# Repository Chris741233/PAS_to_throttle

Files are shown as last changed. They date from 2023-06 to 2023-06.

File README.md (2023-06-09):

# E-bike PAS to throttle converter

Allows you to install a PAS on e-bikes that do not have this port. For those who already have one managed by the controller, also makes it possible to make the starts much more responsive (!) and offers more possibilities of adjustments. A throttle/accelerator input on the controller is required (if no, see also links below).

Permet d'installer un PAS sur les e-bike ne possédant pas ce port. Pour ceux qui en ont déjà un géré par le controleur, permet également de rendre beaucoup plus réactif les démarages (!) et offre plus de possibilités de réglages.
Une entrée throttle/accélérateur sur le controleur est nécessaire (le cas échéant voir aussi liens ci-dessous).

- Conversion de la sortie PAS vers l'entrée throttle (gachette / accélérateur).  
- Possibilité d'utiliser ou non l'assistance proportionnelle en fonction de la vitesse de pédalage.  
- En option inversersion de l'aide  = Plus d'aide en pédalage lent que rapide  
- Le code vérifie le sens de pédalage (pas d'assistance en pédalage arrière !)
- Prise en charge d'une gachette (prioritaire) en option

**see also**  
- [PAS analyzer](https://github.com/Chris741233/PAS_analyzer)
- [Throttle to PAS](https://github.com/Chris741233/throttle-to-PAS)
- [Button to PAS (with cruise in option)](https://github.com/Chris741233/button-to-PAS)

**Discussion sur le forum Cyclurba**  
[Cyclurba](https://cyclurba.fr/forum/forum_discussion.php?from=41&messageID=742211#)

---

 #### Wiring (Arduino Uno/Nano, +5V)

<p align="left">
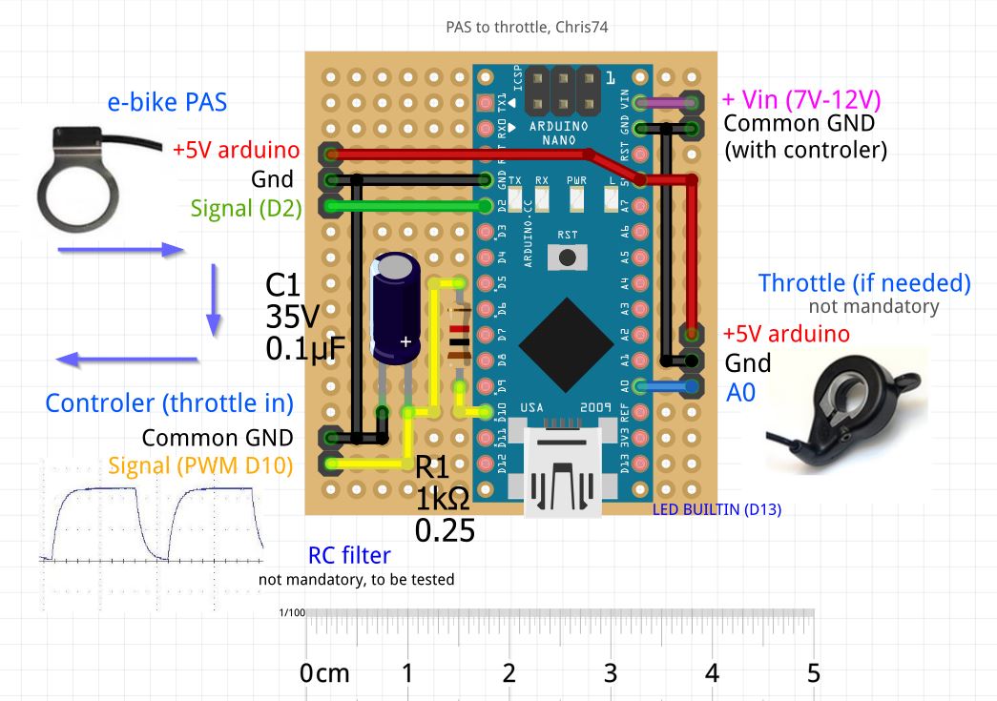
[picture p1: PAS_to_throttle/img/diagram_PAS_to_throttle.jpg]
  
</p>

<p align="left">
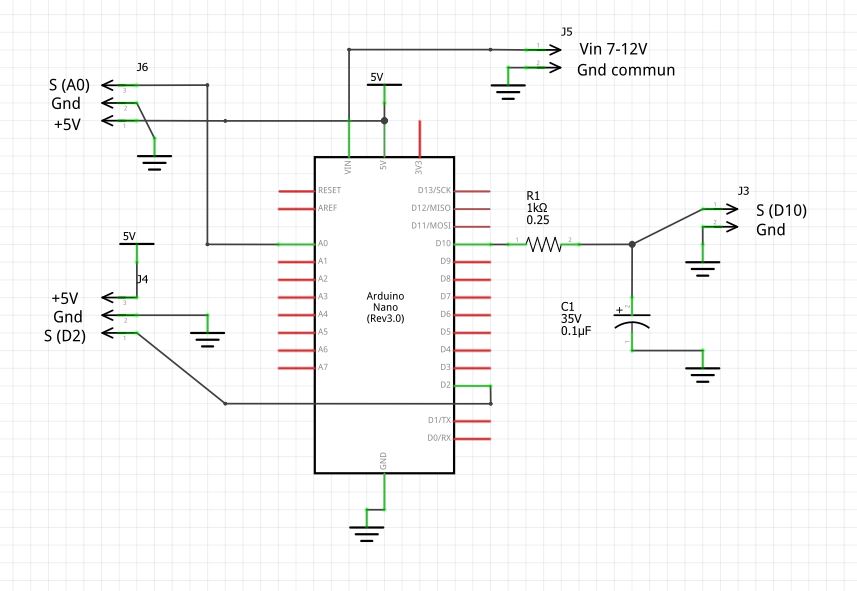
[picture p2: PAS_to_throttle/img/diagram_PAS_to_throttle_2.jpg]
  
</p>

---

#### Usage
*Adjust constants at the beginning of code*\
Régler les constantes en début de code

```
-- Setting ---
#define USE_PROPORTIONAL    0   // use proportional assistance ? 1=yes, 0=no (if no, use only On-Off assistance with full PWM)
#define INVERSE_ASSISTANCE  0   // if proportional, inverse assistance ? 1=yes, 0=no (if yes, slow pedaling = more assistance !)
#define USE_THUMB_THROTTLE  0   // thumb throttle is instaled (see diagram) ? 1=yes, 0=no (throttle priority on the PAS)

const int  NB_MAGNETS =  6;     // How many magnets on PAS ?  (default 6)
const float V_REF =     4.95;   // Arduino +5V pin reference (=PWM high level) - To test! (default 5.00)
const float V_MIN_THR = 1.10;   // throttle min voltage (default 1.1V --- no push)
const float V_MAX_THR = 3.50;   // throttle max voltage (default 3.5V --- full  push)

// throttle (if instaled) --> ADC value, see debug Serial in loop !
const int   TR_ADC_MIN    = 220;    // throttle min - marge ajoutee dans map()
const int   TR_ADC_MAX    = 859;    // throttle max - marge deduite dans map()
const int TR_ADC_MARGIN   = 15;     // margin throttle before send signal PWM and as a deduction of TR_MAX

const int  RPM_TO_START = 10;   // How many RPM to start assistance ? (with default 10, start is normally fast enough)
// --> more rpm = less ms
const int START_PULSES  = 0;    // Number of pulses (magnet) needed before turning On (0 = fastest)
// if use_proportional, RPM value for maping PWM out --> cf map() in void turnOn()
const int RPM_MIN = 25;         // min rpm  (default 25rpm)
const int RPM_MAX = 65;         // max rpm  (default 65rpm)
// interval timer loop: Check RPM, Turn Off, and debug Serial
const int SCAN_INTERVAL = 250;   // default 250, if assistance cut too fast when stop pedaling, put const to ~500ms or 1000ms

```

#### Oscillo and debug Serial
<p align="left">
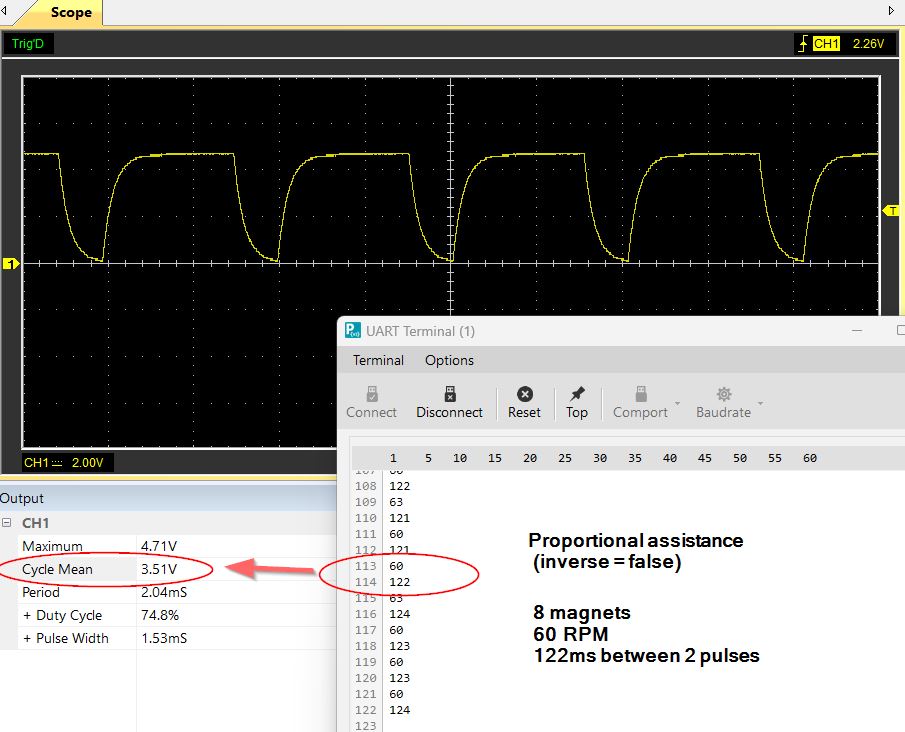
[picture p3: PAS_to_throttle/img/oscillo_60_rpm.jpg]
Oscillo
  
</p>

<br>

<p align="left">
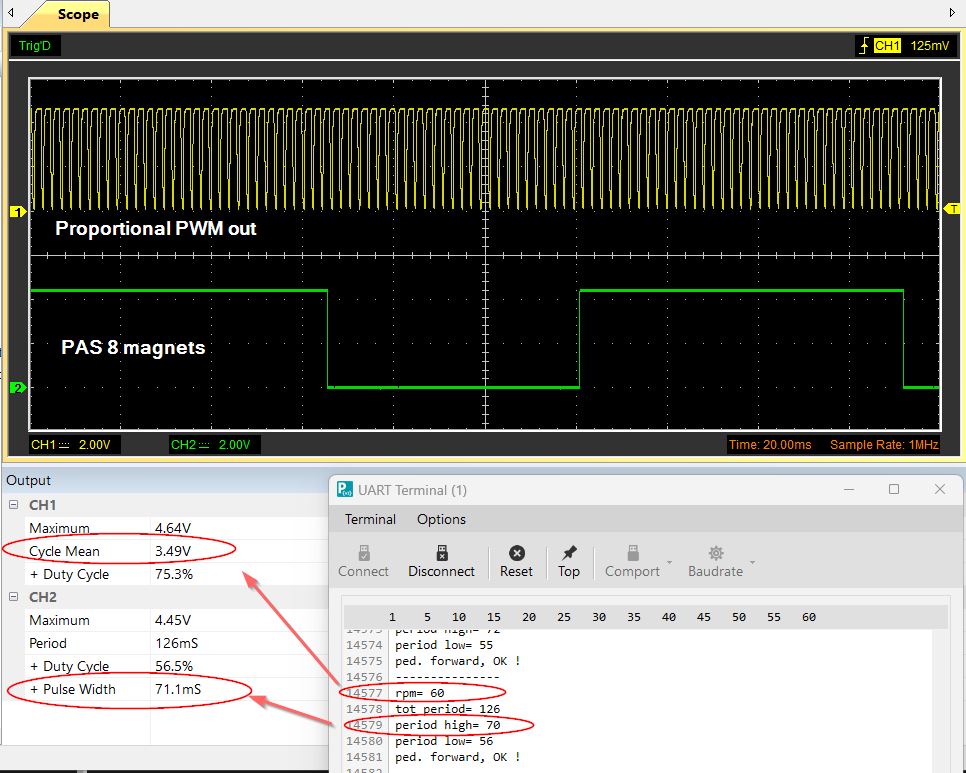
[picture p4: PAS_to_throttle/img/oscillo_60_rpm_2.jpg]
Oscillo
  
</p>

---

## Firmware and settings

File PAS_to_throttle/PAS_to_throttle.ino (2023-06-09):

/******************************************************************
Created with PROGRAMINO IDE for Arduino - 02.06.2023 | 10:21:23
Project     :
Libraries   :
Author      :  Chris74

Description :  e-bike PAS to Throttle

*** Github (code, diagram, infos and more) :  https://github.com/Chris741233/PAS_to_throttle


- Forum Cyclurba : https://cyclurba.fr/forum/742211/arduino-l-assistance-d-un-vae.html?discussionID=31032#msg742211

- Doc PAS ebikes.ca (Signal Types for Basic PAS Sensors) https://ebikes.ca/learn/pedal-assist.html

- Divers : RC Low-pass Filter Design Tool http://sim.okawa-denshi.jp/en/CRtool.php


******************************************************************/

// Install  librairy with Arduino IDE librairy manager or manual (see url)

#include <RunningMedian.h>  // filtre median ou moyennage  https://github.com/RobTillaart/RunningMedian 



// -------- GPIO Arduino Uno/Nano --------------

const int PAS_PIN = 2;   // interrupt (0)  : input from PAS
const int LED_PIN = 13;  // 13 = LED_BUILTIN (controle)

const int PWM_PIN = 10;  // PWM output pin --> to e-bike controler
// PWM signal 490,20 Hz on D3, D9, D10, (or D11 but not on all Nano)
// PWM signal 976,56 Hz on D5 or D6

const int THR_PIN = 0;   // -- THROTTLE A0 (if needed, not mandatory)



// -------- SETTING CONSTANTS (if const float use decimal !) ------------------------

#define USE_PROPORTIONAL    0   // use proportional assistance ? 1=yes, 0=no (if no, use only On-Off assistance with full PWM)
#define INVERSE_ASSISTANCE  0   // if proportional, inverse assistance ? 1=yes, 0=no (if yes, slow pedaling = more assistance !)
// Si inverse, envois plus d'assistance en pédalage lent qu'en pedalage rapide !

#define USE_THUMB_THROTTLE  0   // thumb throttle instaled (see diagram) ? 1=yes, 0=no (throttle priority on the PAS !)

const int  NB_MAGNETS =  6;     // How many magnets on PAS ?  (default 6)

const float V_REF =     4.95;   // Arduino +5V pin reference (=PWM high level) - To test! (default 5.00)
const float V_MIN_THR = 1.10;   // throttle out min voltage (default 1.1V --- no push)
const float V_MAX_THR = 3.50;   // throttle out max voltage (default 3.5V --- full  push)

// thumb throttle (if instaled) --> ADC value, see debug Serial in loop !
const int   TR_ADC_MIN    = 220;    // throttle min (no push) - marge ajoutee dans map()
const int   TR_ADC_MAX    = 859;    // throttle max (full push) - marge deduite dans map()
const int TR_ADC_MARGIN   = 15;     // margin throttle before send signal PWM and as a deduction of TR_ADC_MAX

const int  RPM_TO_START = 10;   // How many RPM to start assistance ? (with default 10, start is normally fast enough)
// --> more rpm = less ms

const int START_PULSES  = 0;    // Number of pulses (magnet) needed before turning On (0 = fastest)

// if use_proportional, RPM value for maping PWM out --> cf map() in void turnOn()
const int RPM_MIN = 25;         // min rpm  (default 25rpm)
const int RPM_MAX = 65;         // max rpm  (default 65rpm)

// interval timer loop: Check RPM, Turn Off, and debug Serial
const int SCAN_INTERVAL = 250;   // default 250, if assistance cut too fast when stop pedaling, put const to ~500ms or 1000ms



// ********** Calculation (don't modif) *********
// -----------------------------------------
const long MS_TO_START = 60000/NB_MAGNETS/RPM_TO_START;  // result en ms. Expl 10rpm and 6 magnets = 1000ms

// PWM 8bit = 5V/255 = 19mV  precision ...
const int MIN_PWM  = V_MIN_THR/V_REF * 255;  // expl:  1.1V / 5.0V * 255 = PWM 56.1 (int 56)
const int MAX_PWM = V_MAX_THR/V_REF * 255;   // expl:  3.5V / 5.0V * 255 = PWM 178.5 (int 178)

const long COEFF_RPM = 60000 / NB_MAGNETS;               // 60000 / 6 magnets  = 10000  (1 minute=60000ms)

const long MS_SLOW = 60000 / RPM_MIN / NB_MAGNETS;       // for maping proportional value
const long MS_FAST = 60000 / RPM_MAX / NB_MAGNETS;       // for maping proportional value



// -------- INIT OBJETS -----------

//  statistic median (median filter)
const int NB_SAMPLE = 10;       // nb. sample median filter (default 10) for thumb throttle
RunningMedian samples_throt = RunningMedian(NB_SAMPLE);  



// -------- GLOBAL VARIABLES ----------------------

unsigned int rpm  = 0;          // RPM pedalling

bool ped_forward = false;       // pedaling forward or backward

bool led_state = false;         // state led controle

bool throt_on = false;          // throttle in use, default false


// -- var Interrupt isr_pas
unsigned long isr_oldtime = 0;

volatile unsigned int period_h = 0;  // volatile obligatoire pour interupt si echange avec autres fonctions
volatile unsigned int period_l = 0;
volatile unsigned int period = 0;

volatile unsigned int pulse = 0;    // PAS pulse count


// -------- MAIN PROG ----------------------

void setup() {
    Serial.begin(115200);
    
    pinMode(LED_PIN, OUTPUT);
    pinMode(PAS_PIN, INPUT_PULLUP);  // PAS Hall, without resistor (input_pullup) !
    
    pinMode(THR_PIN, INPUT);         // thumb throttle, if instaled
    
    digitalWrite(LED_PIN, LOW);      // Led control, low in boot (high if PAS-PWM out)
    
    // -- Interrupt pedaling : appel "isr_pas" sur signal CHANGE (high or low)
    attachInterrupt(digitalPinToInterrupt(PAS_PIN), isr_pas, CHANGE);
    
    // debug const systeme
    Serial.println(MS_TO_START);
    Serial.println(MS_SLOW);
    Serial.println(MS_FAST);
    Serial.println("---------------");
    
    // no delay() here !
    
} //end setup



void loop()
{
    static uint32_t oldtime = millis(); // timer loop, static !
    
    unsigned int val, val_median;
    
    // -- If instaled, read ADC thumb throttle --> throttle priority on the PAS !
    #if  USE_THUMB_THROTTLE == 1
        
        // add sample median filter (10x)
        for(int i=0; i<=NB_SAMPLE-1; i++)
        {
            val = analogRead(THR_PIN);
            samples_throt.add(val);
        }
        val_median = samples_throt.getMedian();
        
        
        // re-map val throttle
        int pwm_throttle = map(val_median, TR_ADC_MIN + TR_ADC_MARGIN, TR_ADC_MAX -TR_ADC_MARGIN, MIN_PWM, MAX_PWM);
        
        if (val_median > TR_ADC_MIN + TR_ADC_MARGIN) {
            throt_on = true;
            analogWrite(PWM_PIN, pwm_throttle);  // PWM out
        }
        else {
            throt_on = false;
            samples_throt.clear();  // reset median filter
        }
        
    #endif
    // -- end thumb throttle
    
    
    // -- pedaling forward or backwards ? (verif si pedalage en avant ou en arriere)
    if (period_h >= period_l) ped_forward = true;
    else ped_forward = false;
    
    
    // -- Turn On only if ...
    if (pulse > START_PULSES && period < MS_TO_START) {
        if (ped_forward) turnOn(); // Turn On only if ped. forward (pedalage en avant !)
    }
    
    // -- Timer loop: Check RPM, Turn Off if no pedalling, and debug Serial
    uint32_t check_t = millis() - oldtime;
    
    if (check_t >= SCAN_INTERVAL) {
        
        oldtime = millis();   // update timer loop
        
        rpm = (pulse * COEFF_RPM) / check_t;
        
        pulse = 0; // reset pulses
        
        // Turn off if no pedaling ...
        if (rpm == 0 || period == 0) {
            turnOff();
        }
        
        // -- debug val thumb throttle
        #if  USE_THUMB_THROTTLE == 1

            //Serial.println(val_median);
            //Serial.println(throt_on);
            //Serial.println("---------------");
            
        #endif
        
        
        // -- debug rpm and period info
        /*
        Serial.print("rpm= ");
        Serial.println(rpm);      // rpm pedalling
        Serial.print("tot period= ");
        Serial.println(period);   // period tot, front to front, in ms
        Serial.print("period high= ");
        Serial.println(period_h); // period high, in ms
        Serial.print("period low= ");
        Serial.println(period_l); // period low, in ms
        if (rpm > 0) {
            if (ped_forward) Serial.println("ped. forward, OK !");
            else Serial.println("ped. backward, no assist !");
        }
        Serial.println("---------------");
        */
        
    } // endif
    
    //Use LED for status info
    digitalWrite(LED_PIN, led_state);
    
    // No delay() here !
    
} // end loop



// -------- FUNCTIONS ----------------------


// -- ISR - interrupt PAS
void isr_pas() {
    
    // rester ici le plus concis possible
    uint32_t isr_time = millis();
    
    if (digitalRead(PAS_PIN) == HIGH) {
        period_l = (isr_time - isr_oldtime);  // ms low (inverse)
        
        pulse++;          // increment nb de pulse (pour calcul rpm)
    }
    else {
        period_h = (isr_time - isr_oldtime);  // ms high (inverse)
    }
    
    period = period_h + period_l;   // tot period
    
    isr_oldtime = isr_time ;        // update timer interupt
    
} // endfunc


// -- Turn off output, reset pulse counter and set state variable to false
void turnOff() {
    
    // noInterrupts();
    detachInterrupt(digitalPinToInterrupt(PAS_PIN)); //  desactiver interrupt,  uniquement pin concernée
    
    pulse    = 0;
    period   = 0;
    period_h = 0;
    period_l = 0;
    
    //interrupts();
    attachInterrupt(digitalPinToInterrupt(PAS_PIN), isr_pas, CHANGE);
    
    analogWrite(PWM_PIN, MIN_PWM);  // PWM minimum
    led_state = false;
    
} // endfunc


// -- Turn on output and set state variable to true
void turnOn() {
    
    int pwm_out;
    
    #if USE_PROPORTIONAL==0
        pwm_out = MAX_PWM;
    #endif
    
    #if USE_PROPORTIONAL==1 && INVERSE == 0
        pwm_out = map(period, MS_SLOW, MS_FAST, MIN_PWM, MAX_PWM);
        if (pwm_out > MAX_PWM) pwm_out=MAX_PWM;
    #endif
    
    #if USE_PROPORTIONAL==1 && INVERSE == 1
        pwm_out = map(period, MS_SLOW, MS_FAST, MAX_PWM, MIN_PWM);
        if (pwm_out > MAX_PWM) pwm_out=MAX_PWM;
    #endif
    
    // -- PAS PWM only if no use of thumb throtle
    #if  USE_THUMB_THROTTLE == 1
        if (throt_on==false) analogWrite(PWM_PIN, pwm_out);
    #else
        analogWrite(PWM_PIN, pwm_out);
    #endif
    
    led_state = true;
    
} // endfunc

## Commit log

2023-06-02 ad files
    [diagram_pas_throttle.fzz]
2023-06-07 add thumb throttle
    [diagram_pas_throttle.fzz]
2023-06-08 cosmetic change
    [diagram_pas_throttle.fzz]
2023-06-08 cosmetics change
    [diagram_pas_throttle.fzz]
